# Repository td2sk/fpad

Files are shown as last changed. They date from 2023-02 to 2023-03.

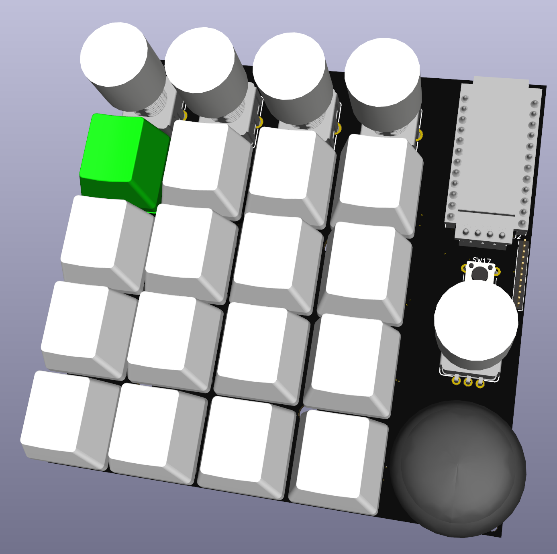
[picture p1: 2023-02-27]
images/fpad.png

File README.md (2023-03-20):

# fpad KiCAD data

fpad

## Features

- Key switch (Cherry MX compatible) x16
- Rotary Encoder - Illuminated (RGB) x5
- JoyStick x1
- Display
- QMK Firmware (TODO)

## License

- MIT License

## Files

- fpad7.kicad_pcb: main board
- fpad_bottom.kicad_pcb: bottom plate
- fpad_top.kicad_pcb: top plate

## Versions

- latest (recommended)
  - in root directory
- rev1 (deprecated)
  - in [releases/rev1](releases/rev1)
  - [errata](releases/rev1/errata.md)

## BOM

| Component | Label | LCSC | remarks |
| --- | --- | --- | --- |
| Capacitor 0.1u 0402 | C1 | C307331  | |
| 1N4148WS Diode SOD-323 x 16 | D1 ~ D16 | C2128 | |
| SK6812MINI-E LED x 16 | LED1 ~ LED16 | C5149201 | |
| SSD1306 OLED Display | OL1 | | |
| Register 7.5kΩ 0402 | R1 | C25918 | |
| Register 100kΩ 3216 | R2 | C17900 | |
| Register 10kΩ 0402 x2 | R3, R4 | C25744 | |
| Register 3.3kΩ 0402 x2 | R5, R6 | C25890 | |
| Rotary Encoder - Illuminated (RGB) x5 | S1 ~ S5 | | https://www.sparkfun.com/products/15141 |
| RKJXV122400R JoyStick | S6 | | https://tech.alpsalpine.com/j/products/detail/RKJXV122400R/ |
| Kailh Switch Socket x16 | SW1 ~ SW16 | C2803348 | CherryMX Compatible |
| Tactile Switch | SW17 | | reset button for ProMicro |
| Arduino ProMicro | U1 | | |
| XL9555 I/O Expander | U2 | C609791  | |
| IS31FL3208A LED Driver | U3 | C2940551 | |

## Issues

- [rev1/errata.md](releases/rev1/errata.md)

## External files

### 3D CONTENTCENTRAL

The following 3D models are obtained from [3D CONTENTCENTRAL](https://www.3dcontentcentral.com/).
They are not included in this repository due to license, so please obtain them on your own and place them in the following paths.

- [Keycap](https://www.3dcontentcentral.com/secure/download-model.aspx?catalogid=171&id=941483)
  - external/3dcontentcentral/Mx_Keycap.step
- [JoyStick](https://www.3dcontentcentral.com/secure/download-model.aspx?catalogid=171&id=1681961)
  - external/3dcontentcentral/User Library-RKJXV122400R.step
- [RotaryEncoder](https://www.3dcontentcentral.com/download-model.aspx?catalogid=171&id=630216)
  - external/3dcontentcentral/User Library-Rotary Encoder v21.STEP

### SnapEDA

SnapEDA files are provided under this license as described in the following [FAQ - SnapEDA](https://www.snapeda.com/about/FAQ/).

### kbd, SparkFun-KiCAD-Libraries

Comply with the original license

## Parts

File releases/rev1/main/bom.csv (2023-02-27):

Designator | Footprint | Quantity | Value | LCSC Part #
C1 | 0402 | 1 | 0.1u | C307331
D1, D10, D11, D12, D13, D14, D15, D16, D2, D3, D4, D5, D6, D7, D8, D9 | D_SOD-323 | 16 | 1N4148WS | C2128
J1 | PinHeader_1x04_P2.54mm_Vertical | 1 | Conn_01x04
J2 | PinHeader_1x12_P1.27mm_Vertical | 1 | Conn_01x12
LED1, LED10, LED11, LED12, LED13, LED14, LED15, LED16, LED2, LED3, LED4, LED5, LED6, LED7, LED8, LED9 | YS-SK6812MINI-E | 16 | YS-SK6812MINI-E
R1 | 0402 | 1 | 7.6k | C4109
R2 | 1206 | 1 | 100k | C17900
R3 | 0402 | 1 | 10k | C25744
S1, S2, S3, S4, S5 | ENCODER_LED_3 | 5 | ENCODER-RGB-SWITCH
S6 | SW_RKJXV122400R | 1 | RKJXV122400R
SW1, SW10, SW11, SW12, SW13, SW14, SW15, SW16, SW2, SW3, SW4, SW5, SW6, SW7, SW8, SW9 | CherryMX_Hotswap | 16 | SW_Push
SW17 | SW_PUSH_6mm_H5mm | 1 | SW_Push
U1 | ProMicro_v3 | 1 | ProMicro_r
U2 | SSOP-24_5.3x8.2mm_P0.65mm | 1 | XL9555 | C609791
U3 | QFN-28-1EP_4x4mm_P0.4mm_EP2.4x2.4mm | 1 | IS31FL3208A | C2940551

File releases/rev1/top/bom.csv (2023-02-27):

Designator | Footprint | Quantity | Value | LCSC Part #
SW2_16, SW2_15, SW2_14, SW2_13, SW2_12, SW2_11, SW2_10, SW2_9, SW2_8, SW2_7, SW2_6, SW2_5, SW2_4, SW2_3, SW2_2, SW2 | SW_Hole | 16 | KEY_SWITCH

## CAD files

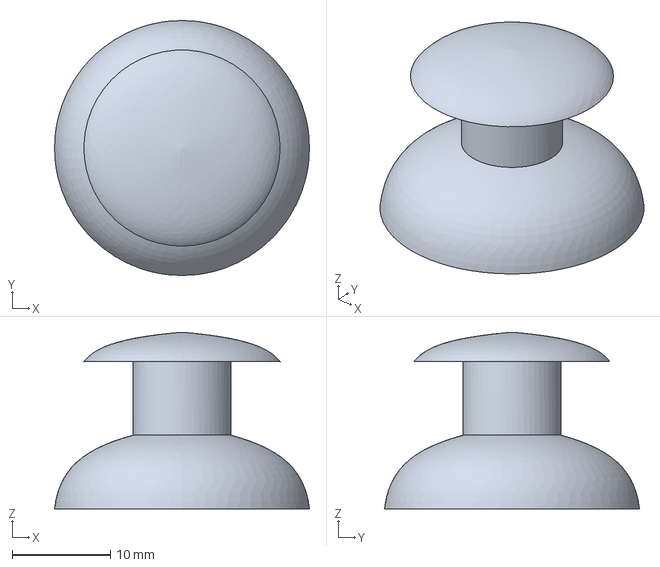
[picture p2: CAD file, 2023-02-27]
my/3D/joystick_head.step
26.0 x 26.0 x 18.0 mm

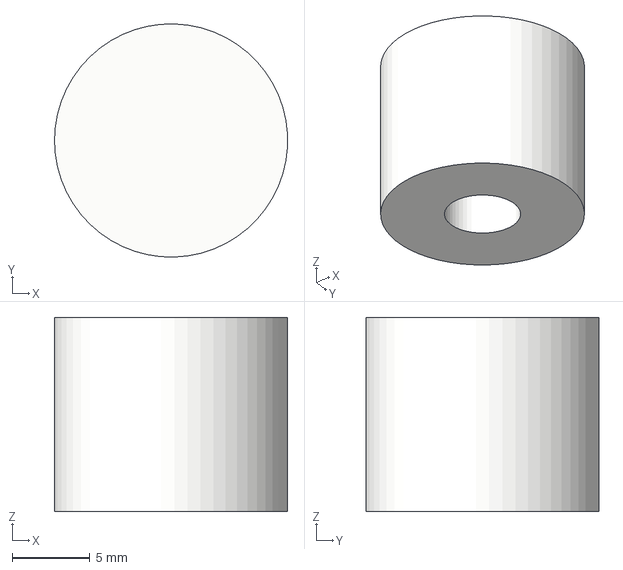
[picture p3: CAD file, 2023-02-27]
my/3D/EC12_transparent_cap.step
15.0 x 15.0 x 12.5 mm

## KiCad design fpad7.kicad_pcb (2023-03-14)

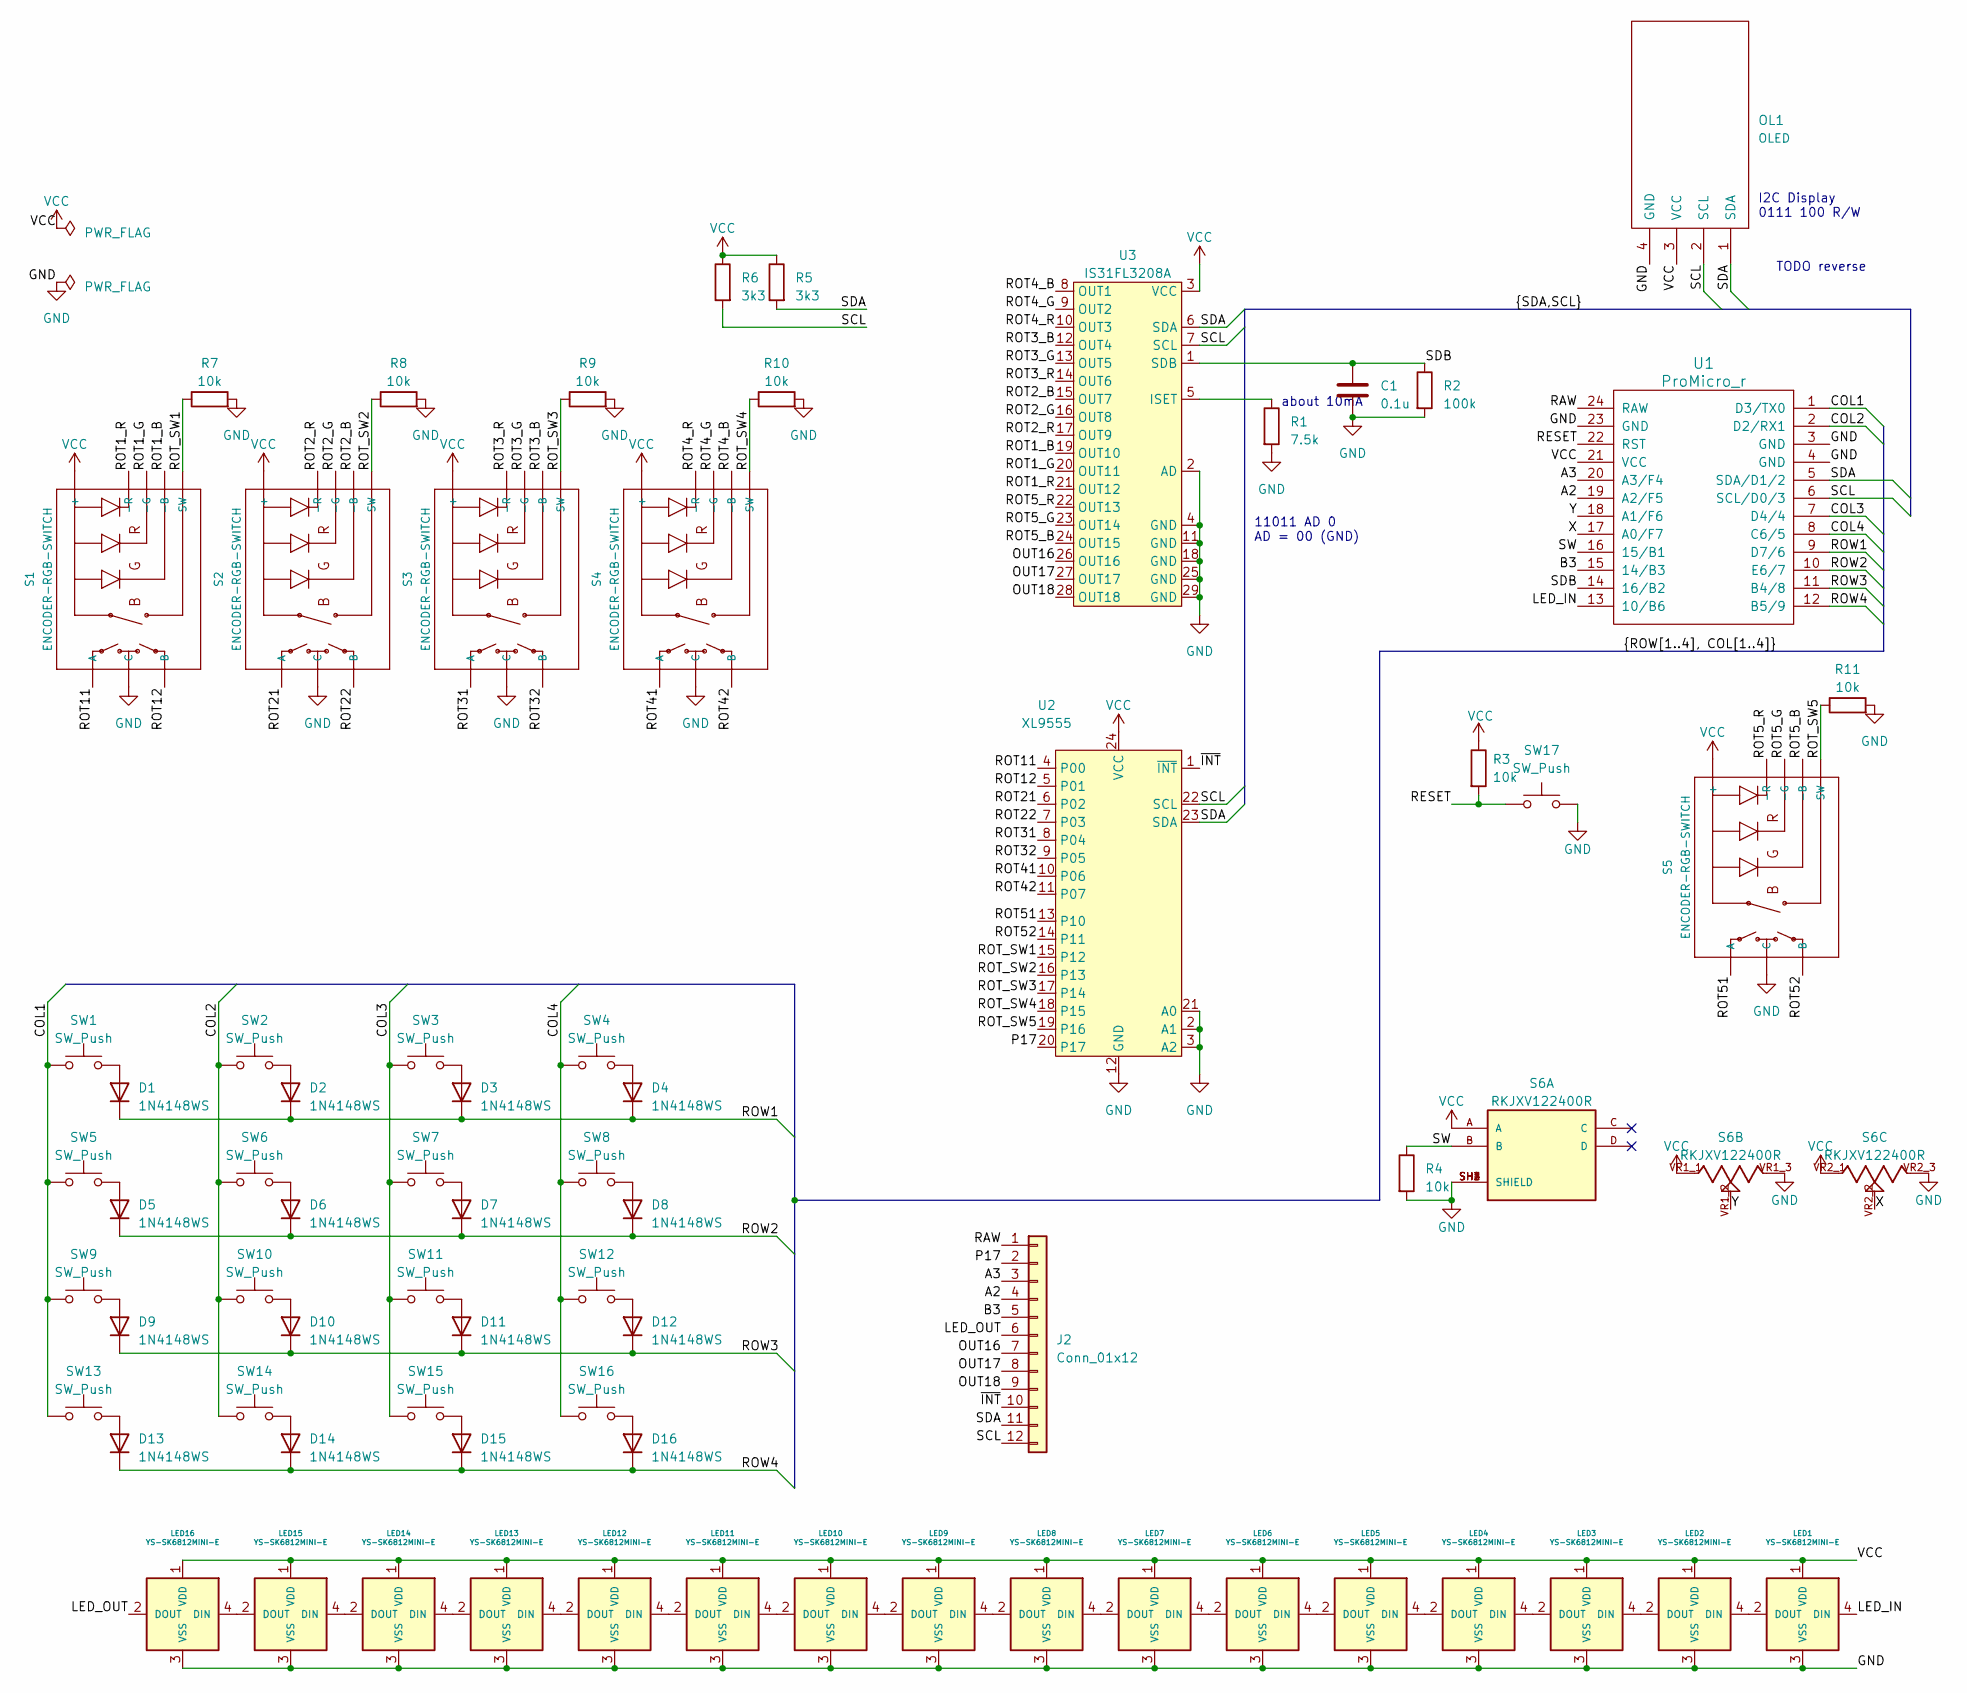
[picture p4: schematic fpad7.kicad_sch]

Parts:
C1: 0.1u; C_0402_1005Metric; LCSC C307331
D1, D2, D3, D4, D5, D6, D7, D8, D9, D10, D11, D12, D13, D14, D15, D16: 1N4148WS; D_SOD-323; LCSC C2128
J2: Conn_01x12; PinHeader_1x12_P1.27mm_Vertical
LED1, LED2, LED3, LED4, LED5, LED6, LED7, LED8, LED9, LED10, LED11, LED12, LED13, LED14, LED15, LED16: YS-SK6812MINI-E
OL1: OLED; OLED_v2
R1: 7.5k; R_0402_1005Metric; LCSC C25918
R2: 100k; R_1206_3216Metric; LCSC C17900
R3, R4, R7, R8, R9, R10, R11: 10k; R_0402_1005Metric; LCSC C25744
R5, R6: 3k3; R_0402_1005Metric; LCSC C25890
S1, S2, S3, S4, S5: ENCODER-RGB-SWITCH; ENCODER_LED_3
S6: RKJXV122400R; SW_RKJXV122400R; PARTREV N/A
SW1, SW2, SW3, SW4, SW5, SW6, SW7, SW8, SW9, SW10, SW11, SW12, SW13, SW14, SW15, SW16: SW_Push; CherryMX_Hotswap
SW17: SW_Push; SW_PUSH_6mm_H5mm
U1: ProMicro_r; ProMicro_v3
U2: XL9555; SSOP-24_5.3x8.2mm_P0.65mm; LCSC C609791
U3: IS31FL3208A; QFN-28-1EP_4x4mm_P0.4mm_EP2.4x2.4mm; LCSC C2940551

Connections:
/A2: J2.4, U1.19 (A2/F5)
/A3: J2.3, U1.20 (A3/F4)
/B3: J2.5, U1.15 (14/B3)
/COL1: SW1.1, SW5.1, SW9.1, SW13.1, U1.1 (D3/TX0)
/COL2: SW2.1, SW6.1, SW10.1, SW14.1, U1.2 (D2/RX1)
/COL3: SW3.1, SW7.1, SW11.1, SW15.1, U1.7 (D4/4)
/COL4: SW4.1, SW8.1, SW12.1, SW16.1, U1.8 (C6/5)
/LED_IN: LED1.4 (DIN), U1.13 (10/B6)
/LED_OUT: J2.6, LED16.2 (DOUT)
/OUT16: J2.7, U3.26 (OUT16)
/OUT17: J2.8, U3.27 (OUT17)
/OUT18: J2.9, U3.28 (OUT18)
/P17: J2.2, U2.20 (P17)
/RAW: J2.1, U1.24 (RAW)
/RESET: R3.2, SW17.1, U1.22 (RST)
/ROT1_B: S1.4 (-B), U3.19 (OUT10)
/ROT1_G: S1.2 (-G), U3.20 (OUT11)
/ROT1_R: S1.1 (-R), U3.21 (OUT12)
/ROT2_B: S2.4 (-B), U3.15 (OUT7)
/ROT2_G: S2.2 (-G), U3.16 (OUT8)
/ROT2_R: S2.1 (-R), U3.17 (OUT9)
/ROT3_B: S3.4 (-B), U3.12 (OUT4)
/ROT3_G: S3.2 (-G), U3.13 (OUT5)
/ROT3_R: S3.1 (-R), U3.14 (OUT6)
/ROT4_B: S4.4 (-B), U3.8 (OUT1)
/ROT4_G: S4.2 (-G), U3.9 (OUT2)
/ROT4_R: S4.1 (-R), U3.10 (OUT3)
/ROT5_B: S5.4 (-B), U3.24 (OUT15)
/ROT5_G: S5.2 (-G), U3.23 (OUT14)
/ROT5_R: S5.1 (-R), U3.22 (OUT13)
/ROT11: S1.A, U2.4 (P00)
/ROT12: S1.B, U2.5 (P01)
/ROT21: S2.A, U2.6 (P02)
/ROT22: S2.B, U2.7 (P03)
/ROT31: S3.A, U2.8 (P04)
/ROT32: S3.B, U2.9 (P05)
/ROT41: S4.A, U2.10 (P06)
/ROT42: S4.B, U2.11 (P07)
/ROT51: S5.A, U2.13 (P10)
/ROT52: S5.B, U2.14 (P11)
/ROT_SW1: R7.1, S1.3 (SW), U2.15 (P12)
/ROT_SW2: R8.1, S2.3 (SW), U2.16 (P13)
/ROT_SW3: R9.1, S3.3 (SW), U2.17 (P14)
/ROT_SW4: R10.1, S4.3 (SW), U2.18 (P15)
/ROT_SW5: R11.1, S5.3 (SW), U2.19 (P16)
/ROW1: D1.1 (K), D2.1 (K), D3.1 (K), D4.1 (K), U1.9 (D7/6)
/ROW2: D5.1 (K), D6.1 (K), D7.1 (K), D8.1 (K), U1.10 (E6/7)
/ROW3: D9.1 (K), D10.1 (K), D11.1 (K), D12.1 (K), U1.11 (B4/8)
/ROW4: D13.1 (K), D14.1 (K), D15.1 (K), D16.1 (K), U1.12 (B5/9)
/SCL: J2.12, OL1.2 (SCL), R6.2, U1.6 (SCL/D0/3), U2.22 (SCL), U3.7 (SCL)
/SDA: J2.11, OL1.1 (SDA), R5.2, U1.5 (SDA/D1/2), U2.23 (SDA), U3.6 (SDA)
/SDB: C1.1, R2.1, U1.14 (16/B2), U3.1 (SDB)
/SW: R4.1, S6.B, U1.16 (15/B1)
/X: S6.VR2_2, U1.17 (A0/F7)
/Y: S6.VR1_2, U1.18 (A1/F6)
/~INT: J2.10, U2.1 (~INT)
GND: C1.2, LED1.3 (VSS), LED2.3 (VSS), LED3.3 (VSS), LED4.3 (VSS), LED5.3 (VSS), LED6.3 (VSS), LED7.3 (VSS), LED8.3 (VSS), LED9.3 (VSS), LED10.3 (VSS), LED11.3 (VSS), LED12.3 (VSS), LED13.3 (VSS), LED14.3 (VSS), LED15.3 (VSS), LED16.3 (VSS), OL1.4 (GND), R1.2, R2.2, R4.2, R7.2, R8.2, R9.2, R10.2, R11.2, S1.C, S2.C, S3.C, S4.C, S5.C, S6.SH1 (SHIELD), S6.SH2 (SHIELD), S6.SH3 (SHIELD), S6.SH4 (SHIELD), S6.VR1_3, S6.VR2_3, SW17.2, U1.3 (GND), U1.4 (GND), U1.23 (GND), U2.2 (A1), U2.3 (A2), U2.12 (GND), U2.21 (A0), U3.2 (AD), U3.4 (GND), U3.11 (GND), U3.18 (GND), U3.25 (GND), U3.29 (GND)
unnamed: D1.2 (A), SW1.2
unnamed: D2.2 (A), SW2.2
unnamed: D3.2 (A), SW3.2
unnamed: D4.2 (A), SW4.2
unnamed: D5.2 (A), SW5.2
unnamed: D6.2 (A), SW6.2
unnamed: D7.2 (A), SW7.2
unnamed: D8.2 (A), SW8.2
unnamed: D9.2 (A), SW9.2
unnamed: D10.2 (A), SW10.2
unnamed: D11.2 (A), SW11.2
unnamed: D12.2 (A), SW12.2
unnamed: D13.2 (A), SW13.2
unnamed: D14.2 (A), SW14.2
unnamed: D15.2 (A), SW15.2
unnamed: D16.2 (A), SW16.2
unnamed: LED1.2 (DOUT), LED2.4 (DIN)
unnamed: LED2.2 (DOUT), LED3.4 (DIN)
unnamed: LED3.2 (DOUT), LED4.4 (DIN)
unnamed: LED4.2 (DOUT), LED5.4 (DIN)
unnamed: LED5.2 (DOUT), LED6.4 (DIN)
unnamed: LED6.2 (DOUT), LED7.4 (DIN)
unnamed: LED7.2 (DOUT), LED8.4 (DIN)
unnamed: LED8.2 (DOUT), LED9.4 (DIN)
unnamed: LED9.2 (DOUT), LED10.4 (DIN)
unnamed: LED10.2 (DOUT), LED11.4 (DIN)
unnamed: LED11.2 (DOUT), LED12.4 (DIN)
unnamed: LED12.2 (DOUT), LED13.4 (DIN)
unnamed: LED13.2 (DOUT), LED14.4 (DIN)
unnamed: LED14.2 (DOUT), LED15.4 (DIN)
unnamed: LED15.2 (DOUT), LED16.4 (DIN)
unnamed: R1.1, U3.5 (ISET)
VCC: LED1.1 (VDD), LED2.1 (VDD), LED3.1 (VDD), LED4.1 (VDD), LED5.1 (VDD), LED6.1 (VDD), LED7.1 (VDD), LED8.1 (VDD), LED9.1 (VDD), LED10.1 (VDD), LED11.1 (VDD), LED12.1 (VDD), LED13.1 (VDD), LED14.1 (VDD), LED15.1 (VDD), LED16.1 (VDD), OL1.3 (VCC), R3.1, R5.1, R6.1, S1.5 (+), S2.5 (+), S3.5 (+), S4.5 (+), S5.5 (+), S6.A, S6.VR1_1, S6.VR2_1, U1.21 (VCC), U2.24 (VCC), U3.3 (VCC)

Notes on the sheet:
TODO reverse
about 10mA
I2C Display 0111 100 R/W
11011 AD 0 AD = 00 (GND)

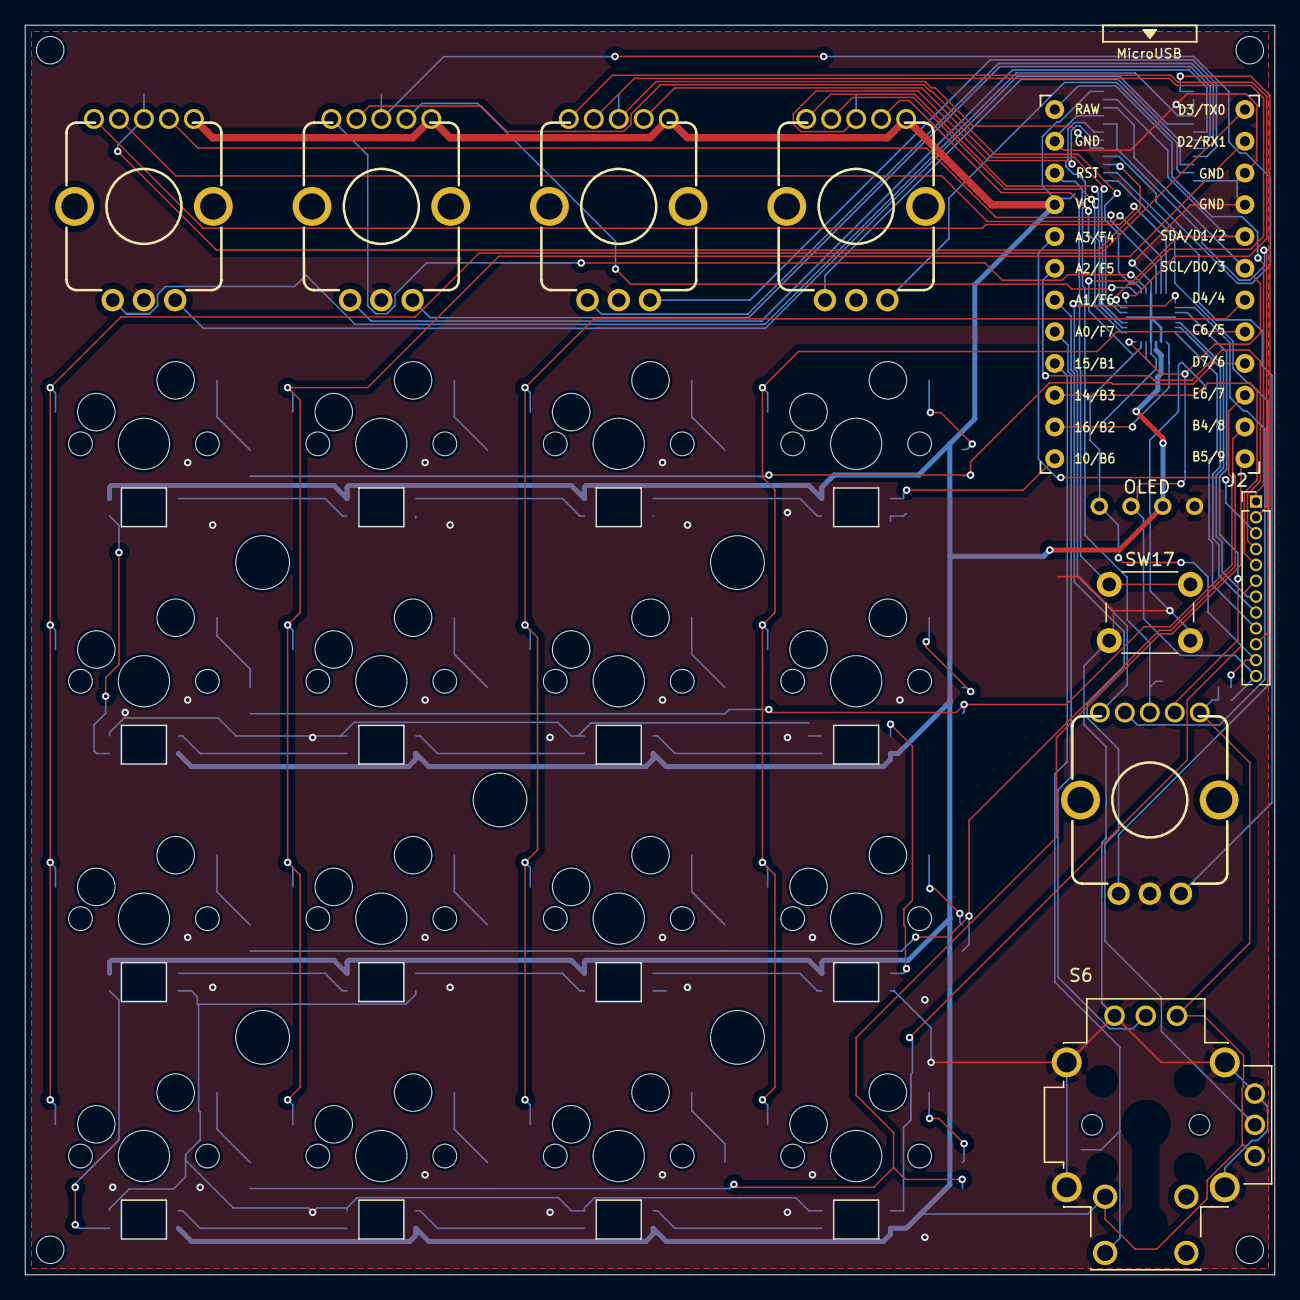
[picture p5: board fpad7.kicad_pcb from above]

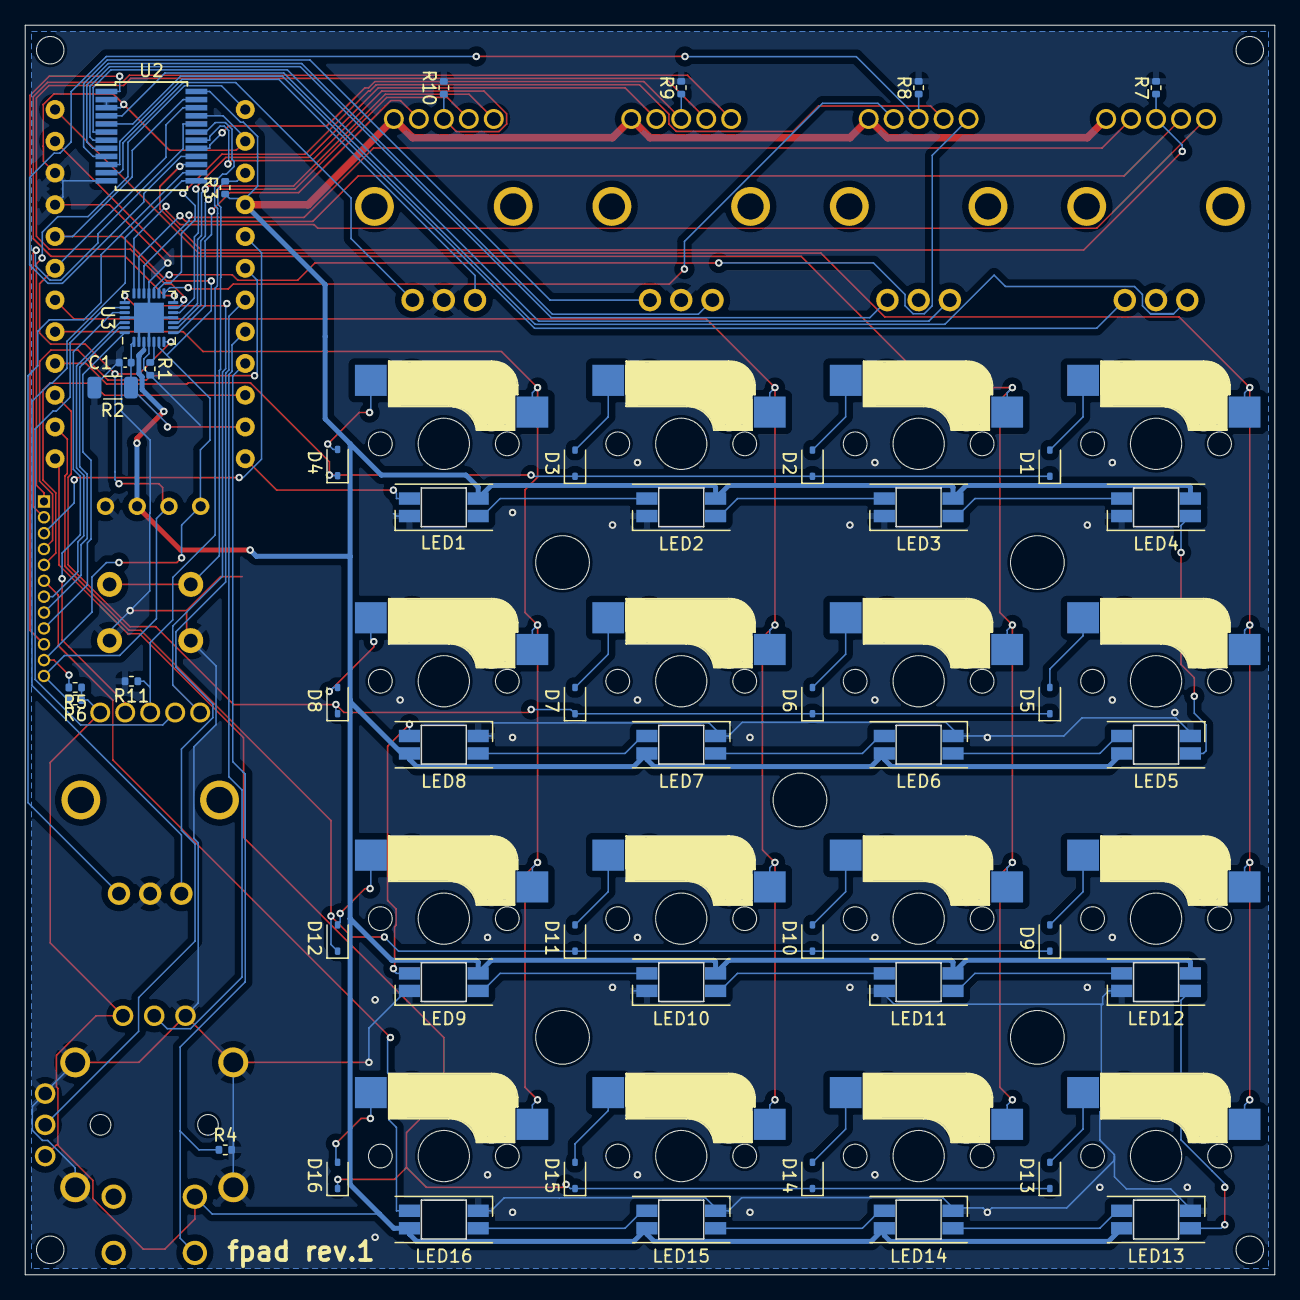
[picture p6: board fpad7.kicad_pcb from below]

Board: 2 copper layers, 100.0 x 100.0 mm, 72 parts (46 on the bottom side), 90 nets.

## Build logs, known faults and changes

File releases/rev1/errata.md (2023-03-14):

# Errata

## Display

- Pin header orientation is reversed incorrectly.

## LED Driver

- VCC line is too thin.

## SW

- need to pull down

## I2C

- need to pull up

## IS31

- 2.2k -> 7.6k
  - workaround
    - set 0x13 to IS31FL3208A reg 0x14 ~ 0x25

## Rotary encoder

- Pin C (voltage base of rotary detection line) should be GND
- Pin 3 (push switch) should be pull down

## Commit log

2023-02-27 add image
    [fpad7.kicad_pcb]
2023-03-12 update: errata for rev1
    [fpad7.kicad_pcb, fpad7.kicad_sch]
2023-03-13 add BOM
2023-03-14 fix: rot sw should be pull down
    [fpad7.kicad_pcb, fpad7.kicad_sch]
2023-03-20 update device image
